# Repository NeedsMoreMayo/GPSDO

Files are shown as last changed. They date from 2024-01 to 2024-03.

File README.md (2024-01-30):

# GPSDO
A GPSDO built around readily available hardware

## Current Status
The GPSDO is a work in progress (Jan 2024). It's the first time I'm working with the AVR-Dx family, and it's looking very promissing.
	
## The GPSDO working principle
I've pulled together a number of designs, and ignored a lot of forum comments. The design uses a NEO-M8N GPS as PPS source, the generated pulse is configurable contrary to some sources. The OCXO is a cheap one. I'm using the Time Integration method (TIC) to tune the crystal. The main source of inspiration is the 2011 design by Kasper Kjeld Pedersen (https://n1.taur.dk/gpsdo2a.pdf).

The OCXO clock is fed to the uC as external clock. This way the control runs synchronous to the XO and we need to measure 2 events to keep the OCXO in check:
- the number of pulses contained within 1 sec of PPS. We can count this with the TCD or TCB counter.
- the fraction of the XO pulse that runs out of phase with the PPS. In other words, the out-of-phaseness of the PPS with the rest of the system. We measure this with a TIC (Time Interpolation Counter)

The corrections are fed to a 18-bit DAC which corrects the voltage control of the OCXO. The phase of the XO isn't adjusted, and doesn't need to be. The 1 PPS envelope contains exactly 10M clocks, and the uC is always synced to the clock.

### TIC

### Output stage
The output driver and clock dividers were copied from Bertrand Zauhar's GPSDO design (https://ve2zaz.net/GPS_Std/Downloads/VE2ZAZ_GPS_Derived_Std_QEX_09_10_2006.pdf). The RS422 line driver is changed to DS34C87T because of rise time/propagation delay considerations. Coupling capacitors are High-Voltage devices.

## Parts
- GPS module: GY-GPSV3 NEO-M8N GPS Module from aliexpress.
- OCXO: OC5SC25
- uC: AVR32DB28
- Output line driver: DS34C87T
- LDO: 2 x AZ1117, one for OCXO and one for digital
- DAC: AD5680

## The AVR-DB uC
I originally planned on building it with an atmega. Then changed my mind to an STM32 with ChibiOS. Now I've chosen AVR32DB28. I hope to become familiar enough with it to help porting ChibiOS to the AVR-DX family.

### Compilation
Just type make, the makefile is a template from WinAVR I adapted.
If your avr-gcc doesn't support this device, you probably need to add the support pack from MicroChip's site:
1. goto http://packs.download.atmel.com/
2. download the Atmel AVR-Dx Series Device Support. It's an archive. Uncompress it in ./xyz/
3. copy ./xyz/gcc/dev/avr32db28/avrxmega3/crtavr32db28.o and libavr32db28.a to /yourGCCAVRpath/avr/lib/avrxmega3/
4. copy ./xyz/gcc/dev/avr32db28/device-specs/specs-avr32db28 to /yourGCCAVRpath/avr/lib/avr-gcc/version/gcc/avr/subversion/device-specs/

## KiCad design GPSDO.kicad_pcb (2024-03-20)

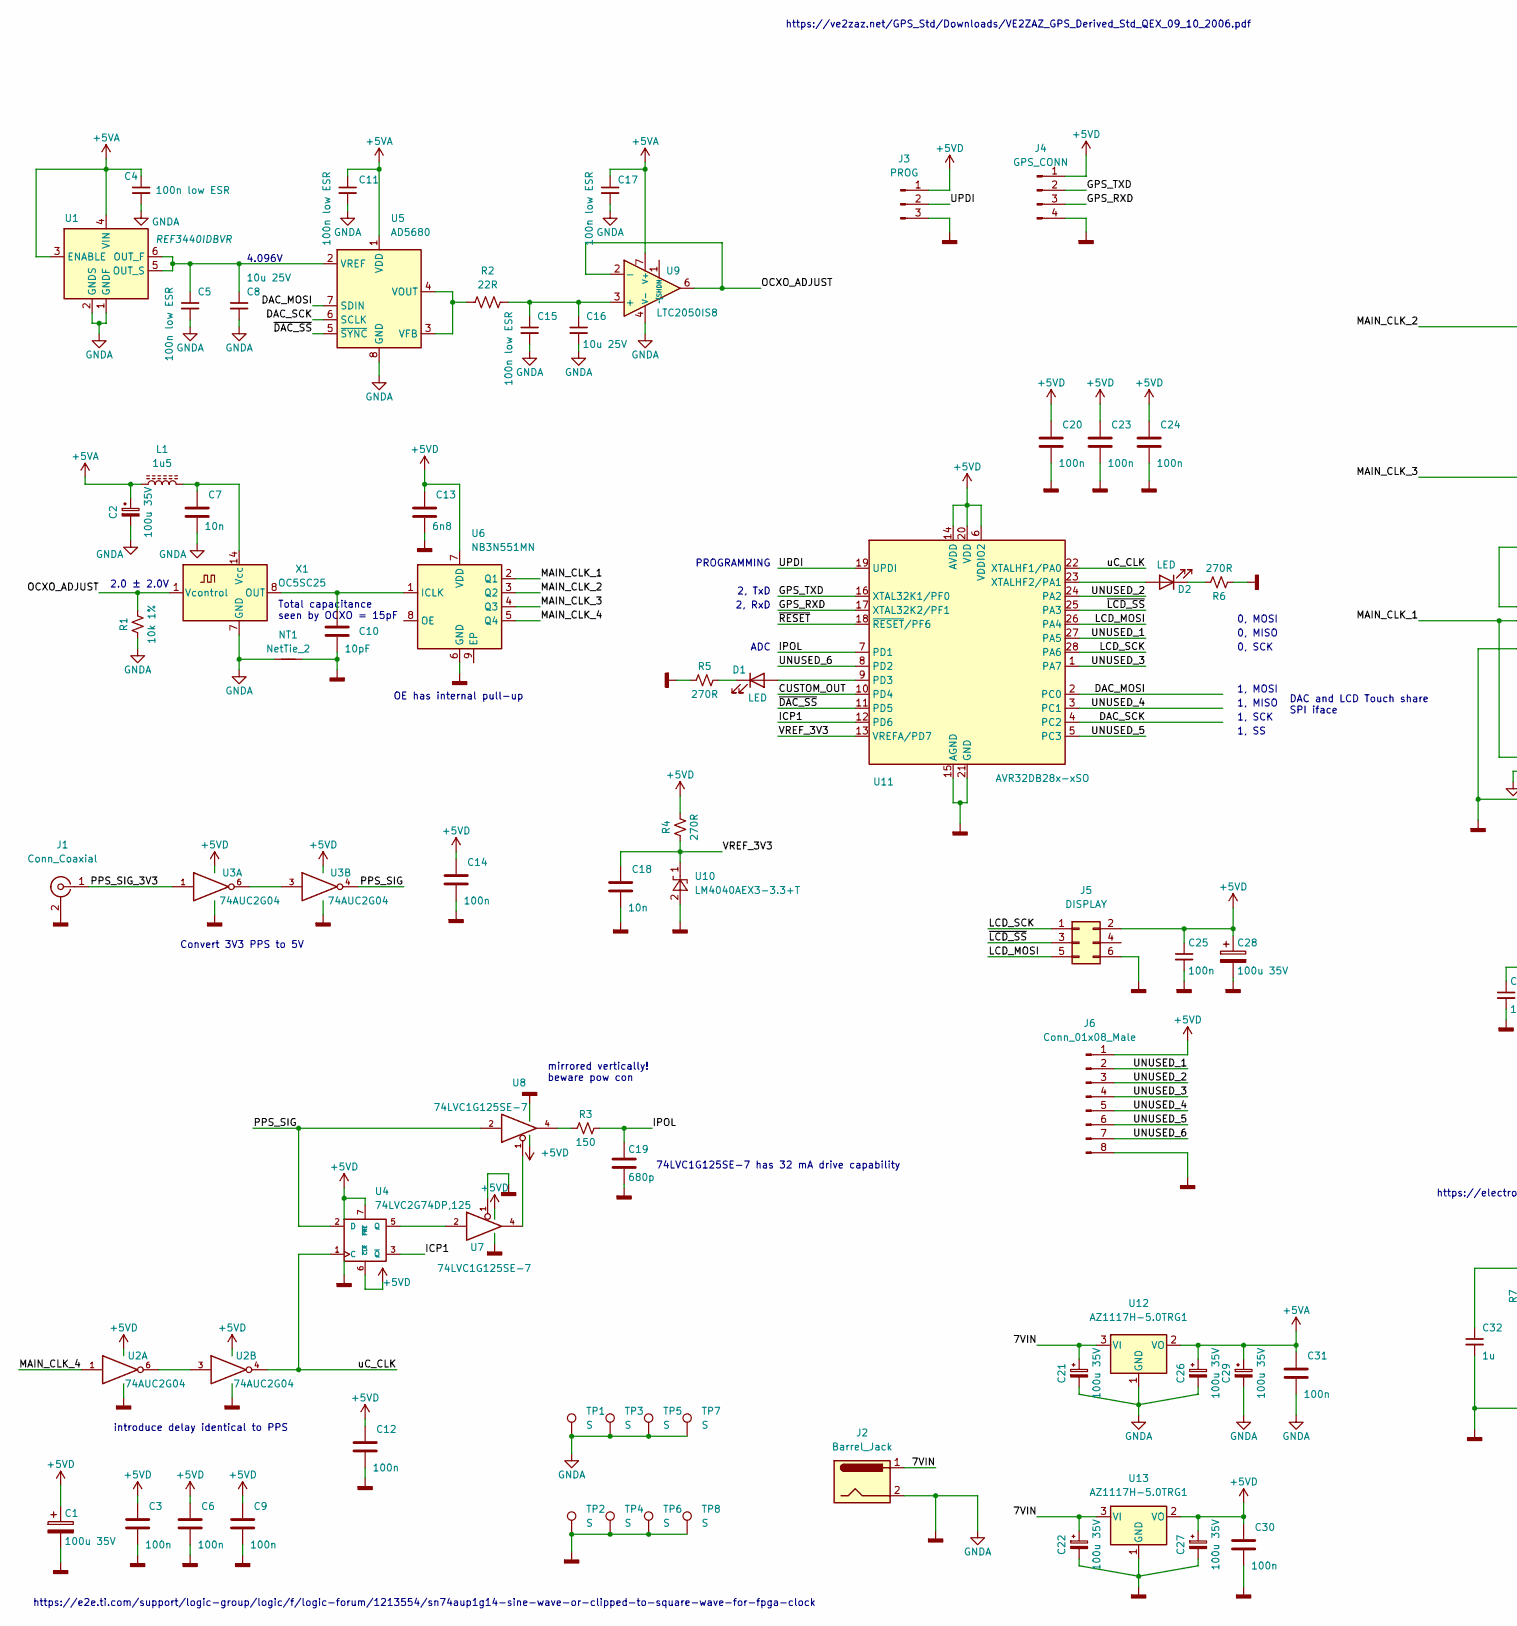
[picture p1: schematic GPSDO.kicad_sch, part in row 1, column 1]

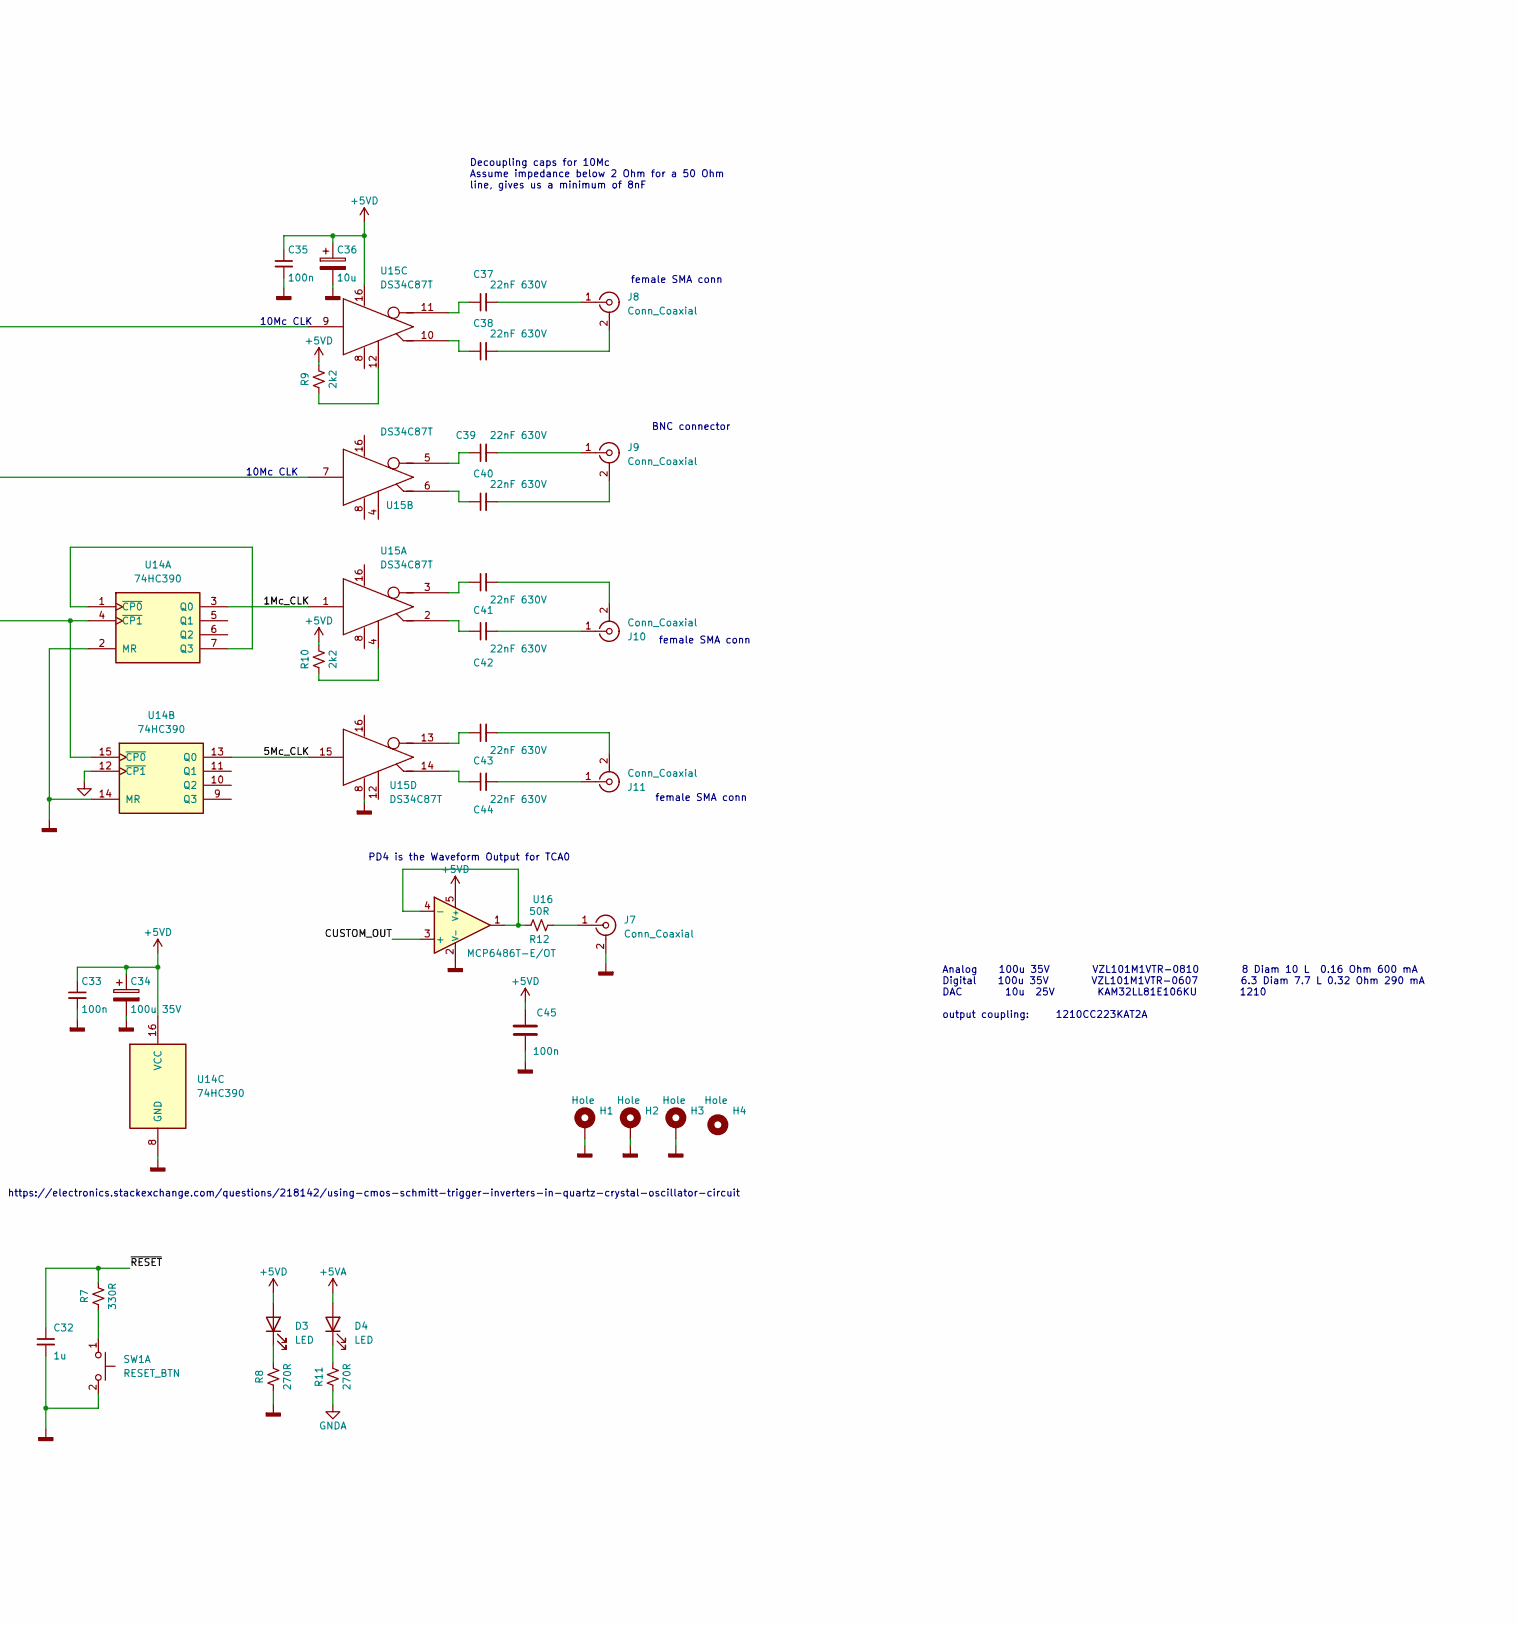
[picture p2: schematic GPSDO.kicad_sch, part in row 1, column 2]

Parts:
C1, C28, C34: 100u 35V; C_Elec_6.3x7.7
C2, C21, C22, C26, C27, C29: 100u 35V; CP_Elec_8x10
C3, C6, C9, C12, C14, C20, C23, C24, C25, C30, C31, C33, C35, C45: 100n; C_0805_2012Metric_Pad1.18x1.45mm_HandSolder
C4, C5, C11, C15, C17: 100n low ESR; C_0805_2012Metric_Pad1.18x1.45mm_HandSolder
C7, C18: 10n; C_0805_2012Metric_Pad1.18x1.45mm_HandSolder
C8, C16: 10u 25V; C_1210_3225Metric_Pad1.33x2.70mm_HandSolder
C10: 10pF; C_0805_2012Metric_Pad1.18x1.45mm_HandSolder
C13: 6n8; C_0805_2012Metric_Pad1.18x1.45mm_HandSolder
C19: 680p; C_0805_2012Metric_Pad1.18x1.45mm_HandSolder
C32: 1u; C_0805_2012Metric_Pad1.18x1.45mm_HandSolder
C36: 10u; C_Elec_4x5.4
C37, C38, C39, C40, C41, C42, C43, C44: 22nF 630V; C_0805_2012Metric_Pad1.18x1.45mm_HandSolder
D1, D2, D3, D4: LED; LED_0805_2012Metric
H1, H2, H3, H4: Hole; MountingHole_3.2mm_M3_Pad_Via
J1: Conn_Coaxial; U.FL_Molex_MCRF_73412-0110_Vertical
J2: Barrel_Jack; BarrelJack_GCT_DCJ200-10-A_Horizontal
J3: PROG; PinHeader_1x03_P2.54mm_Vertical
J4: GPS_CONN; PinHeader_1x04_P2.54mm_Vertical
J5: DISPLAY; PinHeader_2x03_P2.54mm_Vertical
J6: Conn_01x08_Male; PinHeader_2x04_P2.54mm_Vertical
J7, J8, J10, J11: Conn_Coaxial; SMA_Amphenol_901-143_Horizontal
J9: Conn_Coaxial; BNC_TEConnectivity_1478035_Horizontal
L1: 1u5; L_0805_2012Metric
NT1: NetTie_2; SolderJumper-2_P1.3mm_Open_TrianglePad1.0x1.5mm
R1: 10k 1%; R_0805_2012Metric_Pad1.20x1.40mm_HandSolder
R2: 22R; R_0805_2012Metric_Pad1.20x1.40mm_HandSolder
R3: 150; R_0805_2012Metric_Pad1.20x1.40mm_HandSolder
R4, R5, R6, R8, R11: 270R; R_0805_2012Metric_Pad1.20x1.40mm_HandSolder
R7: 330R; R_0805_2012Metric_Pad1.20x1.40mm_HandSolder
R9, R10: 2k2; R_0805_2012Metric_Pad1.20x1.40mm_HandSolder
R12: 50R; R_0805_2012Metric_Pad1.20x1.40mm_HandSolder
SW1: RESET_BTN; BUTTON_5X5
TP1, TP2, TP3, TP4, TP5, TP6, TP7, TP8: S; TestPoint_THTPad_2.0x2.0mm_Drill1.0mm
U1: REF3440IDBVR; SOT-23-6
U2, U3: 74AUC2G04; TSOP-6_1.65x3.05mm_P0.95mm
U4: 74LVC2G74DP,125; TSSOP-8_3x3mm_P0.65mm
U5: AD5680; SOT-23-8_Handsoldering
U6: NB3N551MN; DFN-8-1EP_2x2mm_P0.5mm_EP0.9x1.3mm
U7, U8: 74LVC1G125SE-7; SOT-353_SC-70-5
U9: LTC2050IS8; SO-8_3.9x6.2mm_P1.27mm
U10: LM4040AEX3-3.3+T; SOT-23-3
U11: AVR32DB28x-xSO; SOIC-28W_7.5x17.9mm_P1.27mm
U12, U13: AZ1117H-5.0TRG1; SOT-223-3_TabPin2
U14: 74HC390; SOIC-16_3.9x9.9mm_P1.27mm
U15: DS34C87T; SOIC-16_3.9x9.9mm_P1.27mm
U16: MCP6486T-E/OT; SOT-23-5_HandSoldering
X1: OC5SC25

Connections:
+5VA: C2.1, C4.1, C11.1, C17.1, C26.1, C29.1, C31.2, D4.2 (A), L1.1, U1.3 (ENABLE), U1.4 (VIN), U5.1 (VDD), U9.7 (V+), U12.2 (VO)
+5VD: C1.1, C3.2, C6.2, C9.2, C12.2, C13.2, C14.2, C20.2, C23.2, C24.2, C25.1, C27.1, C28.1, C30.2, C33.1, C34.1, C35.1, C36.1, C45.2, D3.2 (A), J3.1, J4.1, J5.2, J6.1, R4.2, R9.2, R10.2, U2.5 (VCC), U3.5 (VCC), U4.6 (~CLR), U4.7 (~PRE), U4.8 (VCC), U6.7 (VDD), U7.5 (VCC), U8.5 (VCC), U11.6 (VDDIO2), U11.14 (AVDD), U11.20 (VDD), U13.2 (VO), U14.16 (VCC), U15.16 (VCC), U16.5 (V+)
/1Mc_CLK: U14.3 (Q0), U15.1 (INPUT)
/5Mc_CLK: U14.13 (Q0), U15.15 (INPUT)
/7VIN: C21.1, C22.1, J2.1, U12.3 (VI), U13.3 (VI)
/CUSTOM_OUT: U11.10 (PD4), U16.3 (+)
/DAC_MOSI: U5.7 (SDIN), U11.2 (PC0)
/DAC_SCK: U5.6 (SCLK), U11.4 (PC2)
/GPS_RXD: J4.3, U11.17 (XTAL32K2/PF1)
/GPS_TXD: J4.2, U11.16 (XTAL32K1/PF0)
/ICP1: U4.3 (~Q), U11.12 (PD6)
/IPOL: C19.2, R3.1, U11.7 (PD1)
/LCD_MOSI: J5.5, U11.26 (PA4)
/LCD_SCK: J5.1, U11.28 (PA6)
/MAIN_CLK_1: U6.2 (Q1), U14.4 (~CP1), U14.15 (~CP0)
/MAIN_CLK_2: U6.3 (Q2), U15.9 (INPUT)
/MAIN_CLK_3: U6.4 (Q3), U15.7 (INPUT)
/MAIN_CLK_4: U2.1, U6.5 (Q4)
/OCXO_ADJUST: R1.2, U9.2 (-), U9.6, X1.1 (Vcontrol)
/PPS_SIG: U3.4, U4.2 (D), U8.2
/PPS_SIG_3V3: J1.1 (In), U3.1
/UNUSED_1: J6.2, U11.27 (PA5)
/UNUSED_2: J6.3, U11.24 (PA2)
/UNUSED_3: J6.4, U11.1 (PA7)
/UNUSED_4: J6.5, U11.3 (PC1)
/UNUSED_5: J6.6, U11.5 (PC3)
/UNUSED_6: J6.7, U11.8 (PD2)
/UPDI: J3.2, U11.19 (UPDI)
/VREF_3V3: C18.2, R4.1, U10.1 (K), U11.13 (VREFA/PD7)
/uC_CLK: U2.4, U4.1 (C), U11.22 (XTALHF1/PA0)
/~DAC_SS: U5.5 (~SYNC), U11.11 (PD5)
/~LCD_SS: J5.3, U11.25 (PA3)
/~RESET: C32.1, R7.2, U11.18 (~RESET/PF6)
unnamed: D1.2 (A), U11.9 (PD3)
unnamed: D1.1 (K), R5.2
unnamed: D2.2 (A), U11.23 (XTALHF2/PA1)
unnamed: D2.1 (K), R6.2
unnamed: D3.1 (K), R8.2
unnamed: D4.1 (K), R11.2
unnamed: J7.1 (In), R12.1
unnamed: C38.2, J8.2 (Ext)
unnamed: C37.2, J8.1 (In)
unnamed: C40.2, J9.2 (Ext)
unnamed: C39.2, J9.1 (In)
unnamed: C41.2, J10.2 (Ext)
unnamed: C42.2, J10.1 (In)
unnamed: C43.2, J11.2 (Ext)
unnamed: C44.2, J11.1 (In)
unnamed: R3.2, U8.4
unnamed: R7.1, SW1.1 (C)
unnamed: C5.1, C8.1, U1.5 (OUT_S), U1.6 (OUT_F), U5.2 (VREF)
unnamed: U2.3, U2.6
unnamed: U3.3, U3.6
unnamed: U4.5 (Q), U7.2
unnamed: R2.1, U5.3 (VFB), U5.4 (VOUT)
unnamed: C10.2, U6.1 (ICLK), X1.8 (OUT)
unnamed: U7.4, U8.1
unnamed: C15.1, C16.1, R2.2, U9.3 (+)
unnamed: U14.1 (~CP0), U14.7 (Q3)
unnamed: R10.1, U15.4 (ENABLE)
unnamed: C42.1, U15.2 (OUT+)
unnamed: C41.1, U15.3 (OUT-)
unnamed: C40.1, U15.6 (OUT+)
unnamed: C39.1, U15.5 (OUT-)
unnamed: R9.1, U15.12 (ENABLE)
unnamed: C38.1, U15.10 (OUT+)
unnamed: C37.1, U15.11 (OUT-)
unnamed: C44.1, U15.14 (OUT+)
unnamed: C43.1, U15.13 (OUT-)
unnamed: R12.2, U16.1, U16.4 (-)
unnamed: C7.2, L1.2, X1.14 (Vcc)

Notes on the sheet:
10Mc CLK
Analog 100u 35V VZL101M1VTR-0810 8 Diam 10 L 0.16 Ohm 600 mA Digital 100u 35V VZL101M1VTR-0607 6.3 Diam 7.7 L 0.32 Ohm 290 mA DAC 10u 25V KAM32LL81E106KU 1210 output coupling: 1210CC223KAT2A
BNC connector
ADC
1, SS
1, MOSI
Decoupling caps for 10Mc Assume impedance below 2 Ohm for a 50 Ohm line, gives us a minimum of 8nF
0, MOSI
mirrored vertically! beware pow con
DAC and LCD Touch share SPI iface
2, RxD
PROGRAMMING
2.0 ± 2.0V
0, SCK
PD4 is the Waveform Output for TCA0
female SMA conn
1, SCK
4.096V
Total capacitance seen by OCXO = 15pF
introduce delay identical to PPS
0, MISO
1, MISO
OE has internal pull-up
https://electronics.stackexchange.com/questions/218142/using-cmos-schmitt-trigger-inverters-in-quartz-crystal-oscillator-circuit
https://e2e.ti.com/support/logic-group/logic/f/logic-forum/1213554/sn74aup1g14-sine-wave-or-clipped-to-square-wave-for-fpga-clock
https://ve2zaz.net/GPS_Std/Downloads/VE2ZAZ_GPS_Derived_Std_QEX_09_10_2006.pdf
74LVC1G125SE-7 has 32 mA drive capability
2, TxD
Convert 3V3 PPS to 5V

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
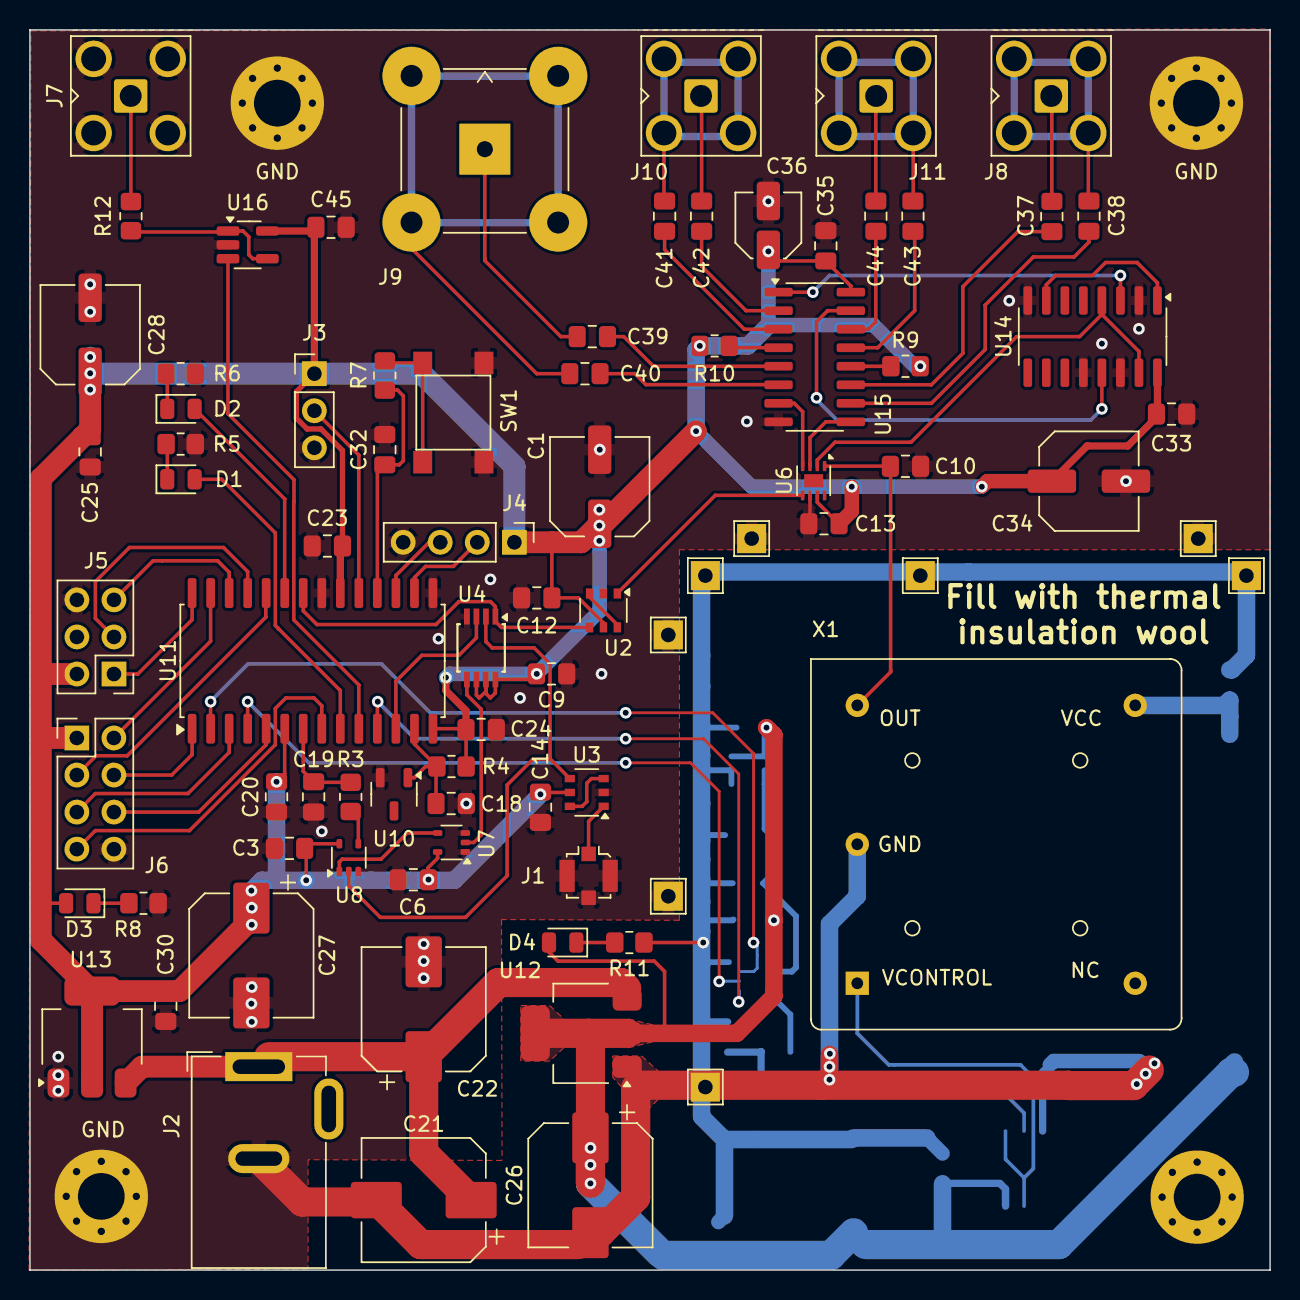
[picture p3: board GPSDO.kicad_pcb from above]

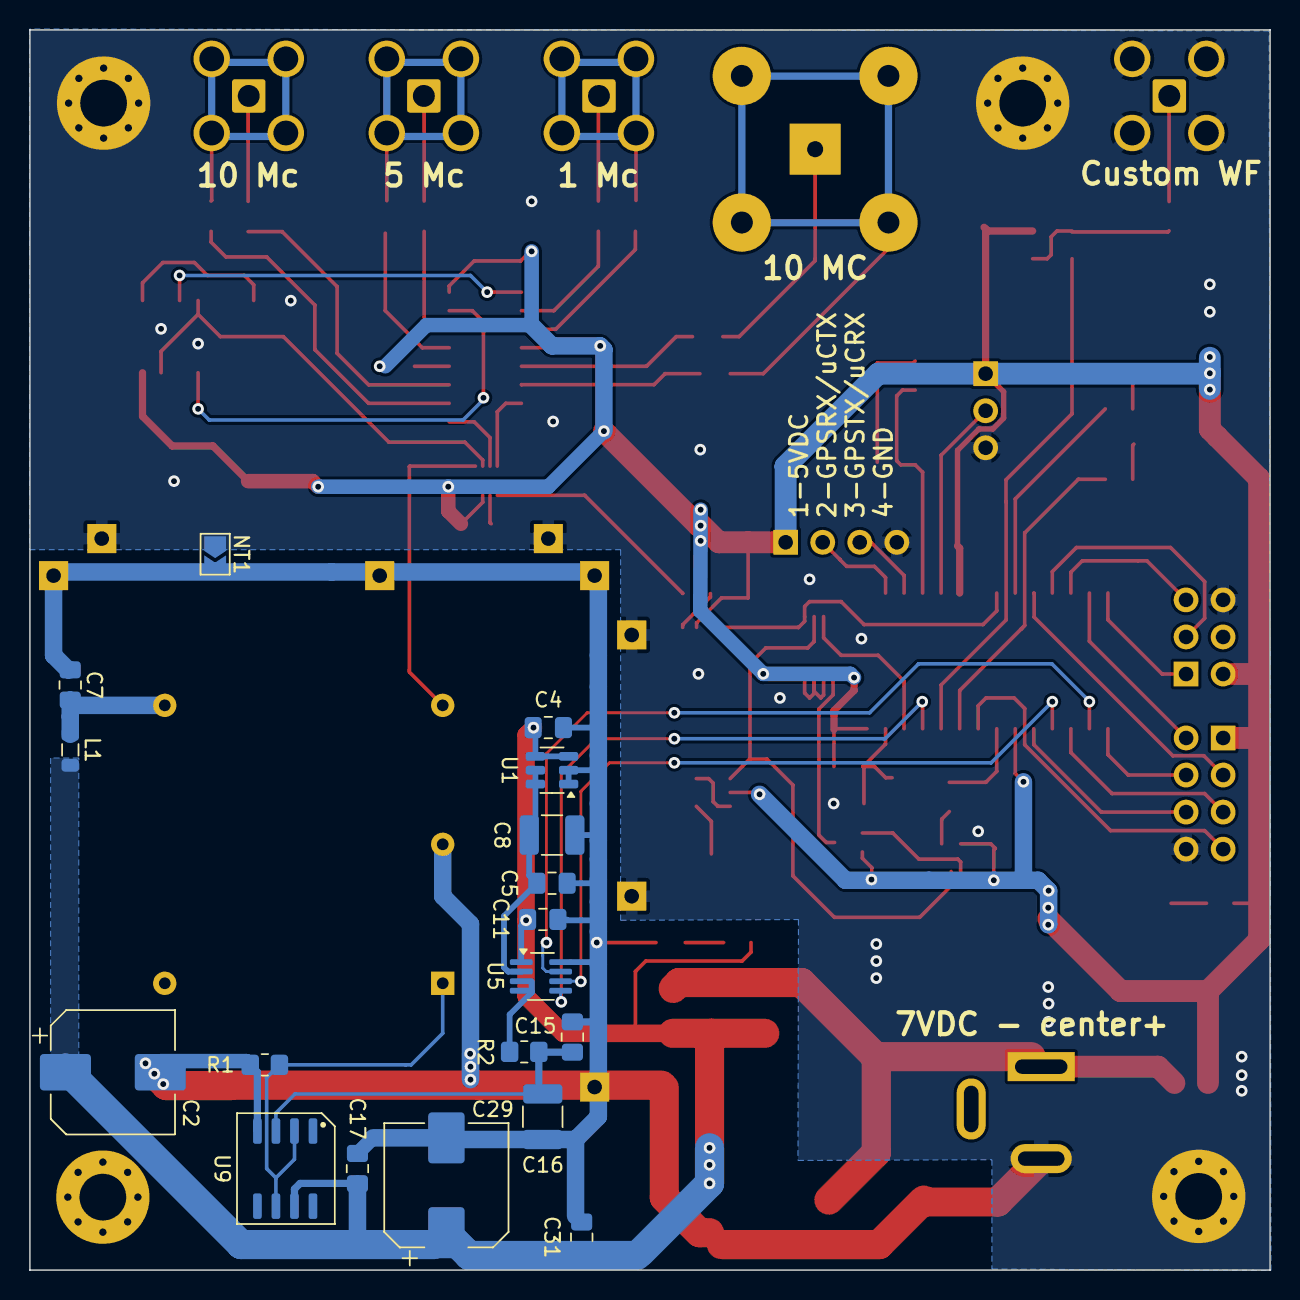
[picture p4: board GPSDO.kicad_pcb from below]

Board: 2 copper layers, 85.0 x 85.0 mm, 104 parts (18 on the bottom side), 72 nets.

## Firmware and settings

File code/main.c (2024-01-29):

//F_CPU defined in makefile
//#define F_CPU 10000000ul

#include <avr/io.h>
#include <util/delay.h>		//temporary sin
#include <avr/interrupt.h>
//#include <math.h>

#include "uart.h"
#include "adc.h"


//PORT A
#define uC_CLK_PIN		0
#define LCD_SS_PIN		1
#define LCD_RESET_PIN	2
#define LCD_DCRS_PIN	3
#define LCD_MOSI_PIN	4
#define LCD_MISO_PIN	5
#define LCD_SCK_PIN		6
#define TOUCH_SS_PIN	7

//PORT C
#define DAC_MOSI_PIN	0
#define TOUCH_MOSI_PIN	0
#define TOUCH_MISO_PIN	1
#define DAC_SCK_PIN		2
#define TOUCH_SCK_PIN	2
#define TOUCH_IRQ_PIN	3

//PORT D
#define IPOL_PIN		1	//ADC0 AIN1
#define DAC_SS_PIN		2
#define LED_PIN			3
#define CUSTOM_OUT_PIN	4
#define ICP1_PIN		5
#define UNUSED_PIN		6
#define VREF_3V3_PIN	7

//PORT F
#define GPS_TXD_PIN		0
#define GPS_RXD_PIN		1
#define RESET_PIN		6

void PORTS_init(void);
void SPI0_init(void);
void SPI1_init(void);
void DAC_init(void);
void LCD_init(void);
void TOUCH_and_DAC_SPI_init(void);
void TOUCH_IRQ_init(void);
void TOGGLE_LED(void);

extern uint8_t ADC_result_available;

int main(void){
	cli(); //disable interrupts when enabling interrupt handlers
	PORTS_init();
	ADC_init();
	TOUCH_IRQ_init();
	USART2_init();
	sei();//enable interrupts
    while (1){
		TOGGLE_LED();
		_delay_ms(1000);
		if(ADC_result_available){
			//process sample
			
		}
    }
}

ISR(PORTC_PORT_vect){
	if(PORTC_INTFLAGS & (1 << TOUCH_IRQ_PIN)){
		//react
		PORTC.INTFLAGS = 1 << TOUCH_IRQ_PIN;
	}
}


void TOGGLE_LED(){
	PORTD.OUTTGL = 1 << LED_PIN;
}

void TOUCH_IRQ_init(){
	//PORTC pin 3
	//no pull-up, interrupt on rising edge (TODO: check display datasheet)
	PORTC.PIN3CTRL = PORT_ISC_RISING_gc;
}

void PORTS_init(){
	//LCD_SS, LCD_RESET, LCD_DCRS, LCD_MOSI, LCD_SCK and TOUCH_SS are output on PORTA
	PORTA.DIR =   (1 << LCD_SS_PIN)
				| (1 << LCD_RESET_PIN)
				| (1 << LCD_DCRS_PIN)
				| (1 << LCD_MOSI_PIN)
				| (1 << LCD_SCK_PIN)
				| (1 << TOUCH_SS_PIN);
	PORTA.OUT = 0x00;
	
	//DAC_MOSI (TOUCH_MOSI), DAC_SCK (TOUCH_SCK) are output on PORTC
	PORTC.DIR =   (1 << DAC_MOSI_PIN)
				| (1 << DAC_SCK_PIN);
	PORTC.OUT = 0x00;
	
	//LED, DAC_SS and CUSTOM_OUT are output on PORTD
	PORTD.DIR =   (1 << LED_PIN)
				| (1 << DAC_SS_PIN)
				| (1 << CUSTOM_OUT_PIN);
	PORTD.OUT = 0x00;
	
	//GPS_TXD is output on PORTD
	PORTF.DIR = 1 << GPS_TXD_PIN;
	PORTF.OUT = 0x00;
}

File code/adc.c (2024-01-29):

#include <avr/io.h>
#include <util/delay.h>		//temporary sin
#include <avr/interrupt.h>

#include "adc.h"

volatile uint8_t ADC_result_available = 0;
volatile adc_result_t ADC_result = 0;


ISR(ADC0_RESRDY_vect){
    // Store the ADC result and notify the main loop
    ADC_result = ADC0.RES;
    ADC_result_available  = 1;
    // The Interrupt flag has to be cleared manually
	// According to 33.5.12 the flag is already cleared by reading the ADC result (?)
    ADC0.INTFLAGS = ADC_RESRDY_bm;
}


void ADC_init(){
	//PORTD1 is Time Interpolation pin
    //Disable digital input buffer .. 18.3.2.1 and 18.3.2.3
	//to reduce noise
    PORTD.PIN1CTRL &= ~PORT_ISC_gm; //INTDISABLE
    PORTD.PIN1CTRL |= PORT_ISC_INPUT_DISABLE_gc; //INPUT_DISABLE
    PORTD.PIN1CTRL &= ~PORT_PULLUPEN_bm; //Disable pull-up resistor
	//tau = 150 * 680 ~= 100ns
	//V = 5V, so at tau we reach max 0.63*5 = 3.15V
	//The board has the footprint for an external Vref at PD7
	//If populated, the ADC ref V is:
	VREF.ADC0REF = VREF_REFSEL_VREFA_gc;
	//If not populated, the best ADC ref V is 4.096V, the diff is 0.946V
	//which is just below 25% of our max value, so we lose 0.5 bits precision:
	//VREF.ADC0REF = VREF_REFSEL_4V096_gc;
	//
	//We measure time IPOL at pin 7, ADC0 AIN1
	ADC0.MUXPOS = ADC_MUXPOS_AIN1_gc;
	//TODO: figure out CLK_PER
	ADC0.CTRLC = ADC_PRESC_DIV4_gc;
	//Just 1 sample, no accumulation
	ADC0.CTRLB= ADC_WINCM_NONE_gc;
	//Enable ADC in 12-bit mode
	ADC0.CTRLA= ADC_ENABLE_bm | ADC_RESSEL_12BIT_gc;
}

void ADC_start(){
	//enable interrupt
	ADC0.INTCTRL = ADC_RESRDY_bm;
	//start conversion
	ADC0.COMMAND = ADC_STCONV_bm;
	//TODO: change pin to digital output and write 0 to discharge the capacitor
}

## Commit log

2024-01-20 Updated schematic
    [GPSDO.kicad_pcb, GPSDO.kicad_sch]
2024-01-20 Added pulse delay in TIC
    [GPSDO.kicad_pcb, GPSDO.kicad_sch]
2024-01-20 selected TIC components
    [GPSDO.kicad_pcb, GPSDO.kicad_sch]
2024-01-20 Added LEDs, modified SPI
    All SPI uses the same interface now.
    Added extra clocksource to a gpio pin, I don't know whether the internal systick timer will be configurable enough to count ticks
    [GPSDO.kicad_pcb, GPSDO.kicad_sch]
2024-01-20 some pcb placing
    finding optimal location on the pcb
    [GPSDO.kicad_pcb, GPSDO.kicad_sch]
2024-01-21 LCD conn
    Updated LCD & touch connector
    [GPSDO.kicad_pcb, GPSDO.kicad_sch]
2024-01-21 Update .gitignore
    ignore kicad backup files
2024-01-21 Updated output stage and a few bugs
    Different driver, some layout moving
    [GPSDO.kicad_pcb, GPSDO.kicad_sch]
2024-01-21 Update README.md
    Output stage
2024-01-21 finalised schematic
    no more big changes
    [GPSDO.kicad_pcb, GPSDO.kicad_sch]
2024-01-21 minor adjustments
    [GPSDO.kicad_pcb, GPSDO.kicad_sch]
2024-01-22 Re-assigned pins
    Preparing for tracing
    Added an UFL output for an arbitrary clock out from the uC. Undecided on PCB dimensions ... will probably change from line driver to RS422 driver and go for a wider PCB
    [GPSDO.kicad_pcb, GPSDO.kicad_sch]
2024-01-23 updated pcb
    more shuffling
    [GPSDO.kicad_pcb, GPSDO.kicad_sch]
2024-01-23 component placement
    inching towards completion
    [GPSDO.kicad_pcb, GPSDO.kicad_sch]
2024-01-24 LDO power supply
    preliminary component choice
    [GPSDO.kicad_pcb, GPSDO.kicad_sch]
2024-01-24 minor update
    [GPSDO.kicad_pcb, GPSDO.kicad_sch]
2024-01-25 intermediate solution for layout
    [GPSDO.kicad_pcb, GPSDO.kicad_sch]
2024-01-25 0CXO chamber complete
    [GPSDO.kicad_pcb]
2024-01-25 first routing
    [GPSDO.kicad_pcb, GPSDO.kicad_sch]
2024-01-25 DRC & ground planes
    [GPSDO.kicad_pcb, GPSDO.kicad_sch]
2024-01-25 moved components down to accomodate GPS receiver
    [GPSDO.kicad_pcb]
2024-01-26 GPS module position
    Moved GPS UART connector to 35.1 mm from edge to connect straight to chassis. PCB mounting hole can however not be used.
    [GPSDO.kicad_pcb, GPSDO.kicad_sch]
2024-01-26 makefile & code setup
    [GPSDO.kicad_sch]
2024-01-27 Corrected schematic: VREF
    VREF was chosen as 5V instead of 4.096V - corrected with REF3440IDBVR
    [GPSDO.kicad_pcb, GPSDO.kicad_sch]
2024-01-27 TODO: ref/ADC/opamp placement
    The layout for those components is far from optimal
    [GPSDO.kicad_pcb]
2024-01-27 Flip-flop error
    Wrong device, wasn't 5V tolerant. Corrected
    [GPSDO.kicad_pcb, GPSDO.kicad_sch]
2024-01-27 changed flipflop & added vref
    Flip-flop doesn't really benefit from having a set/reset that can be changed.
    uC benefits from having an external reference. If not placed, internal one can be used.
    [GPSDO.kicad_pcb, GPSDO.kicad_sch]
2024-01-27 updated LCD layout
    [GPSDO.kicad_pcb, GPSDO.kicad_sch]
2024-01-27 updated layout
    Added vref footprint
    Changed pour params for better gnd coverage
    increased digital line distances
    [GPSDO.kicad_pcb, GPSDO.kicad_sch]
2024-01-28 updated code
    added ADC init code
2024-01-28 Re-layout of Vref-OPAMP-DAC
    made analog connections shorter
    [GPSDO.kicad_pcb]
2024-01-28 added ADC ISR
2024-01-28 Added Touch IRQ handler
    AVR-DX GPIO interrupts get grouped per PORT ... you check them in the ISR. Weird.
2024-01-29 Added a second LED to GPIO & layout cleanup
    [GPSDO.kicad_pcb, GPSDO.kicad_sch]
2024-01-29 Flipped barrel ground: GND and GNDA, added bottom texts
    [GPSDO.kicad_pcb, GPSDO.kicad_sch]
2024-01-29 ADC and UART code in seperate sources
2024-01-30 Differential pairs leaving the drivers are equal in length
    difference is in the order 0.01 mm
    [GPSDO.kicad_pcb, GPSDO.kicad_sch]
2024-02-01 Final version
    Added custom footprints and symbols (OCXO ...)
    [GPSDO.kicad_pcb]
2024-02-06 Change of Display
    Changed display interface to one that drives an SPI module (expander) so that a cheap LCD can be used. Then one can put whatever display on it.
    [GPSDO.kicad_pcb, GPSDO.kicad_sch]
2024-02-07 Added vias in the power lines
    [GPSDO.kicad_pcb]
2024-02-10 Updated 5VA tracks
    [GPSDO.kicad_pcb]
2024-02-10 5VA and 5VD seperation removed now that layouting finished
    [GPSDO.kicad_sch]
2024-02-10 cleaning up pour zones
    [GPSDO.kicad_pcb]
2024-03-19 Minor aesthetic edits
    Upgraded to Kicad 7.2
    Updated several footprints and changed a few power supply track widths
    [GPSDO.kicad_pcb, GPSDO.kicad_sch]
2024-03-20 Gerbers and final version
    [GPSDO-B_Cu.gbl, GPSDO-B_Mask.gbs, GPSDO-B_Paste.gbp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]
